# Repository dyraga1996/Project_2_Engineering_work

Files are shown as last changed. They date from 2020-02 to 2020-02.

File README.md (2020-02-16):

# Project_2_Engineering_work
Design and implementation of an access control system using RFID technology. 
The system will consist of three components: 
- an electronic device
- a program written in C++ language for the microcontroller
- a web server on which the Internet application and the MySQL database will be located.

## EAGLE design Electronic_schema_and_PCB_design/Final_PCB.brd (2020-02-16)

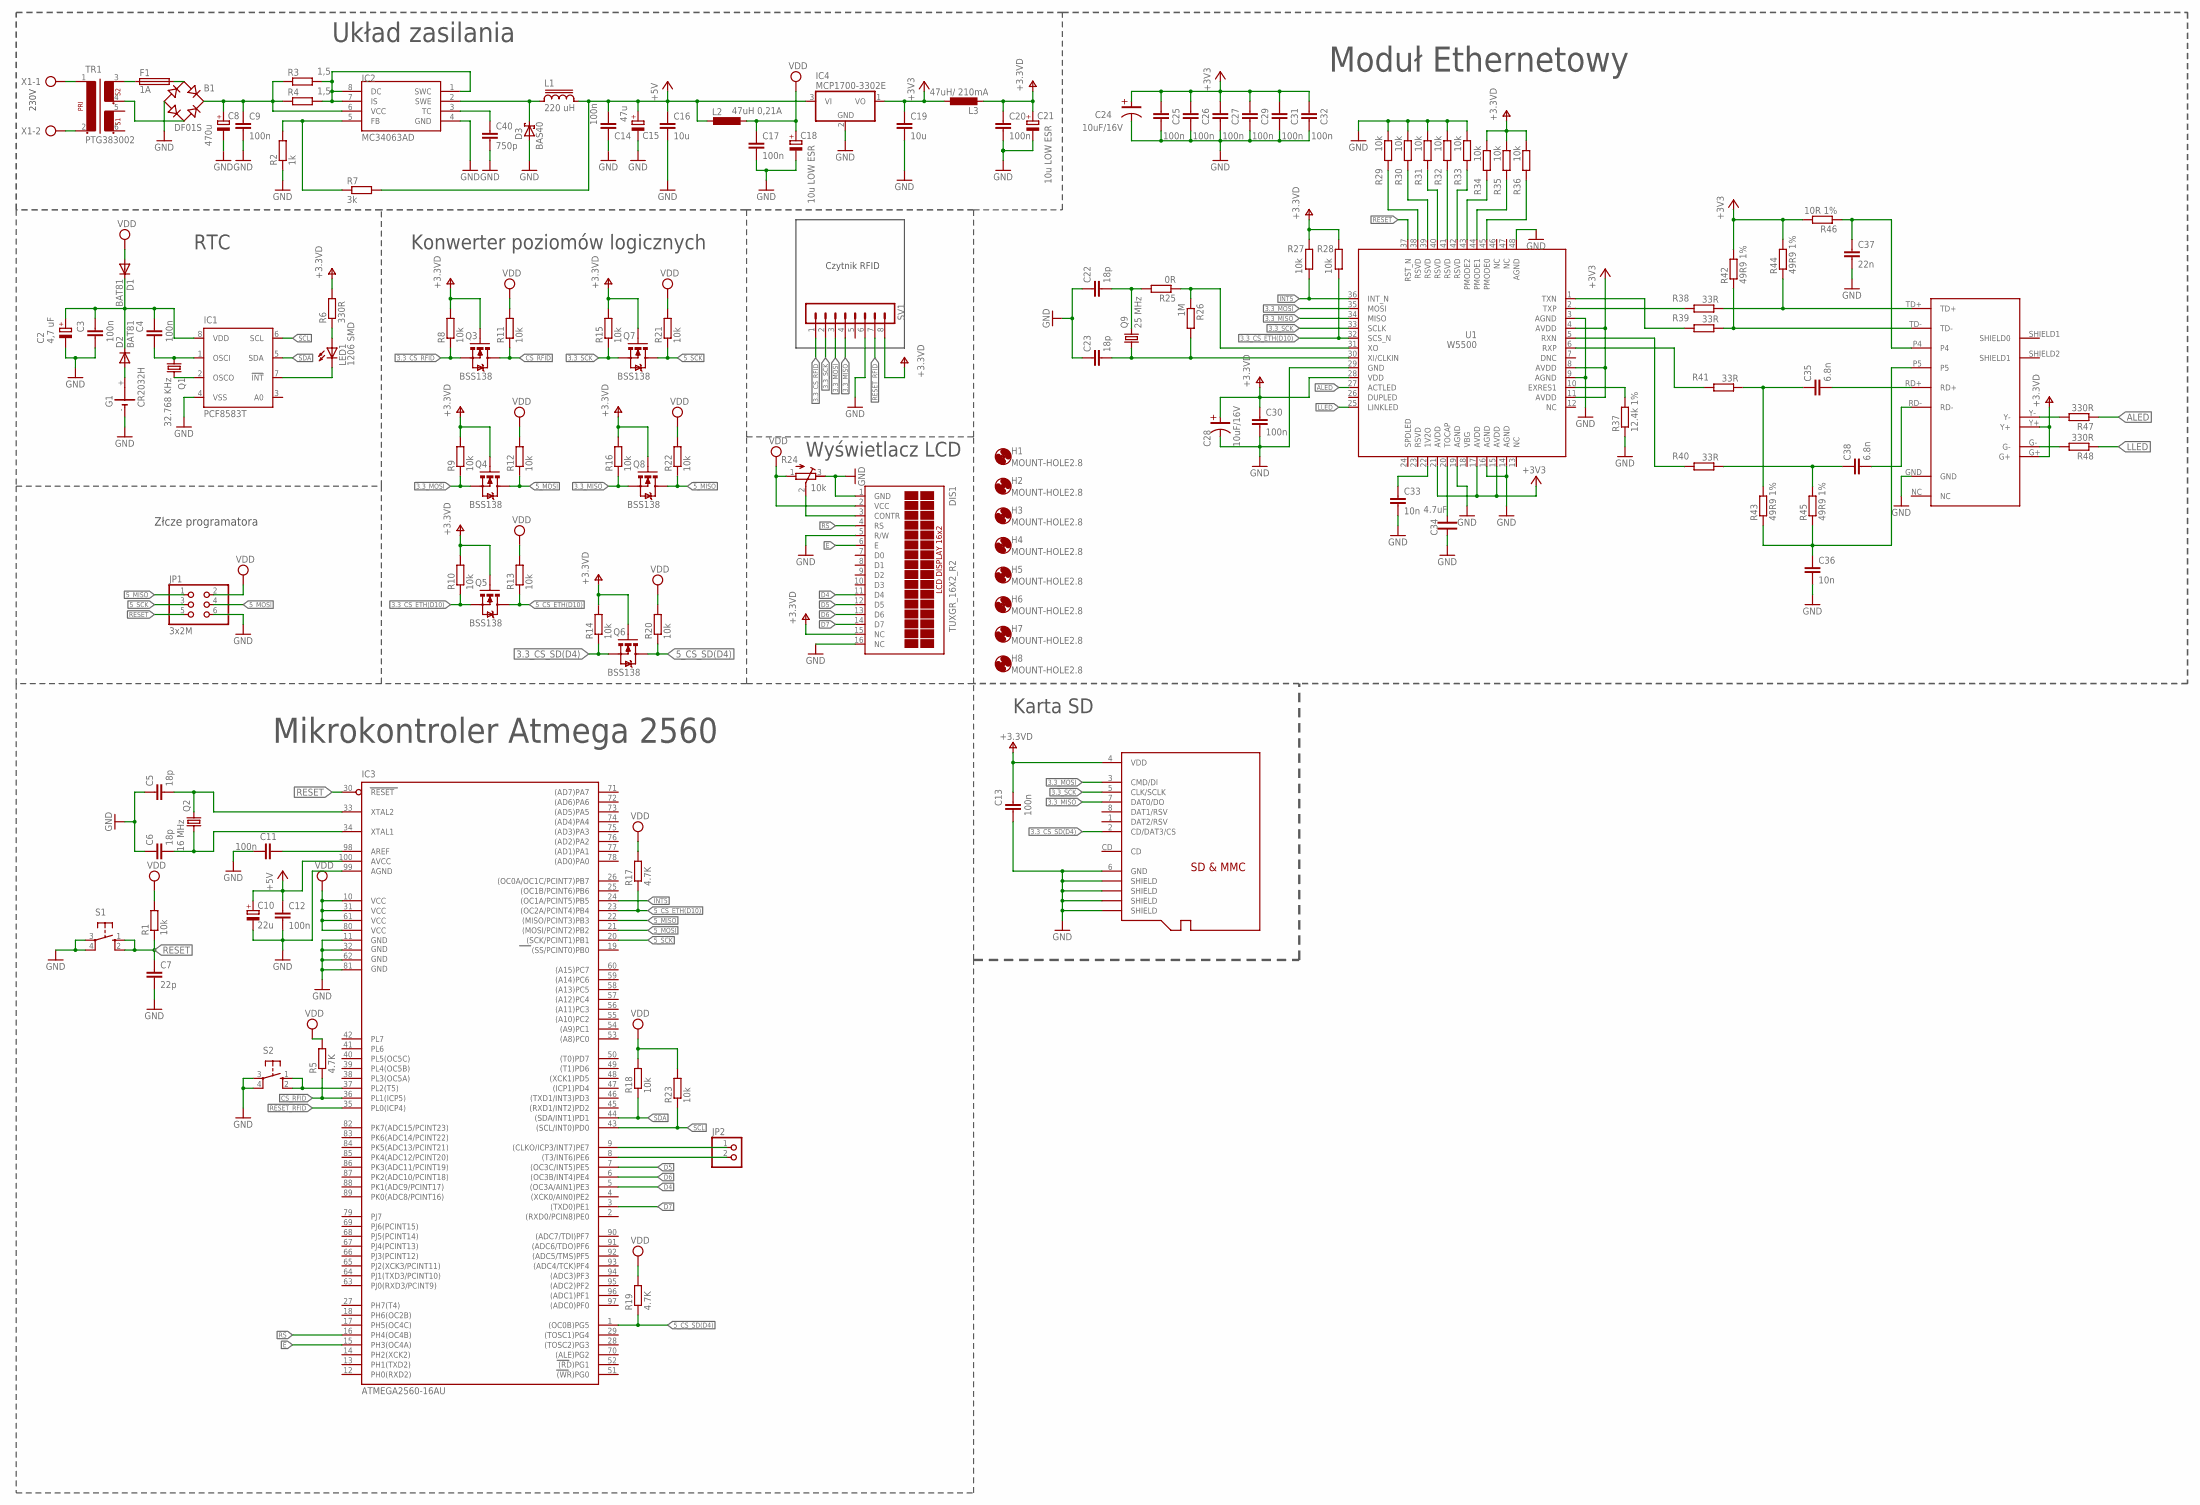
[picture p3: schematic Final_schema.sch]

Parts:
B1: DF01S; DB
C2: 4,7 uF; UD-5X5,8_NICHICON
C3, C4, C9, C12, C13, C14, C25, C26, C27, C29, C31, C32: 100n; C0603
C5, C6, C22, C23: 18p; C0603
C7: 22p; C0603
C8: 470u; E7,5-16
C10: 22u; UD-5X5,8_NICHICON
C11: 100n; C0603-ROUND
C15: 47u; 153CLV-0505
C16, C19: 10u; C0603
C17, C20, C30: 100n; C0603K
C18, C21: 10u LOW ESR; E5-10,5
C24, C28: 10uF/16V; C-3216(TANTAL)
C33, C36: 10n; C0603
C34: 4.7uF; C-2012
C35, C38: 6.8n; C0603
C37: 22n; C0603
C40: 750p; C0603K
D1, D2: BAT81; DO34-7
D3: BAS40; SOT23
DIS1: TUXGR_16X2_R2
F1: 1A; GSH15
G1: CR2032H
H1, H2, H3, H4, H5, H6, H7, H8: MOUNT-HOLE2.8; 2,8
IC1: PCF8583T; SO8-7_5
IC2: MC34063AD; SOIC8
IC3: ATMEGA2560-16AU; TQFP100
IC4: MCP1700-3302E; TO92
JP1: 3x2M; 2X03
JP2: D5; 1X02
L1: 220 uH; CD54
L2: 47uH 0,21A; L1812
L3: 47uH/ 210mA; L1812
LED1: 1206 SMD; LED_1206
Q1: 32.768 KHz; TC26H
Q2: 16 MHz; HC49/S
Q3, Q4, Q5, Q6, Q7, Q8: BSS138; SOT23-3
Q9: 25 MHz; HC49/S
R1, R8, R9, R10, R11, R12, R13, R14, R15, R16, R18, R20, R21, R22, R23, R27, R28, R29, R30, R31, R32, R33, R34, R35, R36: 10k; R0603
R2: 1k; R0603
R3, R4: 1,5; 0411/15
R5, R17, R19: 4.7K; R0603
R6, R47, R48: 330R; R0603
R7: 3k; R0603
R24: 10k; RTRIM4G/J
R25: 0R; R0603
R26: 1M; R0603
R37: 12.4k 1%; R0603
R38, R39, R40, R41: 33R; R0603
R42, R43, R44, R45: 49R9 1%; R0603
R46: 10R 1%; R0603
S1: SW3; B3F-10XX
S2: SW; B3F-10XX
SV1: RC522; MA08-1
TR1: PTG383002; VR12
U1: W5500
U$1: HR911105A; RJ45
U$2: MICROSD; C12075
X1: 230V; AK500/2-H

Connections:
3.3_CS_ETH(D10): Q5.2 (S), R10.1, R28.1, U1.32 (SCS_N)
3.3_CS_RFID: Q3.2 (S), R8.1, SV1.1
3.3_CS_SD(D4): Q6.2 (S), R14.1, U$2.2 (CD/DAT3/CS)
3.3_MISO: Q8.2 (S), R16.1, SV1.4, U1.34 (MISO), U$2.7 (DAT0/DO)
3.3_MOSI: Q4.2 (S), R9.1, SV1.3, U1.35 (MOSI), U$2.3 (CMD/DI)
3.3_SCK: Q7.2 (S), R15.1, SV1.2, U1.33 (SCLK), U$2.5 (CLK/SCLK)
5_CS_ETH(D10): IC3.23 ((OC2A/PCINT4)PB4), Q5.3 (D), R13.1, R17.1
5_CS_SD(D4): IC3.1 ((OC0B)PG5), Q6.3 (D), R19.1, R20.1
5_MISO: IC3.22 ((MISO/PCINT3)PB3), JP1.1, Q8.3 (D), R22.1
5_MOSI: IC3.21 ((MOSI/PCINT2)PB2), JP1.4, Q4.3 (D), R12.1
5_SCK: IC3.20 ((SCK/PCINT1)PB1), JP1.3, Q7.3 (D), R21.1
+3V3: C19.1, C24.1, C25.1, C26.1, C27.1, C29.1, C31.1, C32.1, IC4.1 (VO), L3.1, R42.2, R44.2, R46.2, U1.4 (AVDD), U1.8 (AVDD), U1.11 (AVDD), U1.15 (AVDD), U1.17 (AVDD), U1.21 (AVDD)
+5V: C10.+, C12.1, C14.1, C15.+, C16.1, IC3.100 (AVCC), IC4.3 (VI), L1.2, L2.2, R7.2
ALED: R47.1, U1.27 (ACTLED)
AREF: C11.1, IC3.98 (AREF)
CS_RFID: IC3.36 (PL1(ICP5)), Q3.3 (D), R5.1, R11.1
D4: DIS1.11 (D4), IC3.5 ((OC3A/AIN1)PE3)
D5: DIS1.12 (D5), IC3.7 ((OC3C/INT5)PE5)
D6: DIS1.13 (D6), IC3.6 ((OC3B/INT4)PE4)
D7: DIS1.14 (D7), IC3.3 ((TXD0)PE1)
E: DIS1.6 (E), IC3.15 (PH3(OC4A))
GND: B1.-, C2.-, C3.2, C5.1, C6.1, C7.2, C8.-, C9.2, C10.-, C11.2, C12.2, C13.2, C14.2, C15.-, C16.2, C17.2, C18.-, C19.2, C20.2, C21.-, C22.1, C23.1, C24.2, C25.2, C26.2, C27.2, C28.2, C29.2, C30.2, C31.2, C32.2, C33.2, C34.P$1, C36.2, C37.2, C40.2, D3.1 (A), DIS1.1 (GND), DIS1.5 (R/W), DIS1.16 (NC), G1.-, IC1.4 (VSS), IC2.4 (GND), IC3.11 (GND), IC3.32 (GND1), IC3.62 (GND2), IC3.81 (GND3), IC3.99 (AGND), IC4.2 (GND), JP1.6, R2.1, R24.3 (E), R29.2, R30.2, R31.2, R32.2, R33.2, R37.1, S1.3, S1.4 (P1), S2.3, S2.4 (P1), SV1.6, U1.3 (AGND), U1.9 (AGND), U1.14 (AGND), U1.16 (AGND), U1.19 (AGND), U1.29 (GND), U1.48 (AGND), U$1.GND, U$2.6 (GND), U$2.GND@1 (SHIELD), U$2.GND@2 (SHIELD), U$2.GND@3 (SHIELD), U$2.GND@4 (SHIELD)
INT5: IC3.24 ((OC1A/PCINT5)PB5), R27.1, U1.36 (INT_N)
LLED: R48.1, U1.25 (LINKLED)
unnamed: IC1.7 (!INT), LED1.C
unnamed: R29.1, U1.38 (RSVD)
unnamed: IC2.5 (FB), R2.2, R7.1
unnamed: IC2.1 (SWC), IC2.7 (IS), IC2.8 (DC), R3.2, R4.2
unnamed: D3.3 (C), IC2.2 (SWE), L1.1
unnamed: C40.1, IC2.3 (TC)
unnamed: TR1.1, X1.1
unnamed: TR1.2, X1.2
unnamed: B1.AC1, F1.2
unnamed: B1.AC2, TR1.4 (5)
unnamed: F1.1, TR1.3 (6)
unnamed: B1.+, C8.+, C9.1, IC2.6 (VCC), R3.1, R4.1
unnamed: R47.2, U$1.Y-
unnamed: R41.2, U1.6 (RXP)
unnamed: DIS1.3 (CONTR), R24.2 (S)
unnamed: R30.1, U1.39 (RSVD)
unnamed: R31.1, U1.40 (RSVD)
unnamed: C22.2, Q9.2, R25.2
unnamed: IC3.9 ((CLKO/ICP3/INT7)PE7), JP2.1
unnamed: IC3.8 ((T3/INT6)PE6), JP2.2
unnamed: R48.2, U$1.G-
unnamed: IC3.37 (PL2(T5)), S2.1 (S), S2.2 (S1)
unnamed: C4.2, IC1.1 (OSCI), Q1.1
unnamed: IC1.2 (OSCO), Q1.2
unnamed: D2.A, G1.+
unnamed: C2.+, C3.1, C4.1, D1.C, D2.C, IC1.8 (VDD)
unnamed: R32.1, U1.41 (RSVD)
unnamed: R33.1, U1.42 (RSVD)
unnamed: R34.1, U1.43 (PMODE2)
unnamed: R35.1, U1.44 (PMODE1)
unnamed: R36.1, U1.45 (PMODE0)
unnamed: C34.P$2, U1.20 (TOCAP)
unnamed: C33.1, U1.22 (1V2O)
unnamed: R37.2, U1.10 (EXRES1)
unnamed: C37.1, R46.1, U$1.P4
unnamed: C35.2, U$1.RD+
unnamed: C38.2, U$1.RD-
unnamed: C36.1, R43.1, R45.1, U$1.P5
unnamed: LED1.A, R6.1
unnamed: R25.1, R26.1, U1.31 (XO)
unnamed: R40.2, U1.5 (RXN)
unnamed: R38.2, U1.2 (TXP)
unnamed: R39.2, U1.1 (TXN)
unnamed: C23.2, Q9.1, R26.2, U1.30 (XI/CLKIN)
RESET: C7.1, IC3.30 (RESET), JP1.5, R1.1, S1.1 (S), S1.2 (S1), U1.37 (RST_N)
RESET_RFID: IC3.35 (PL0(ICP4)), SV1.7
RS: DIS1.4 (RS), IC3.16 (PH4(OC4B))
RXN: C38.1, R40.1, R45.2
RXP: C35.1, R41.1, R43.2
SCL: IC1.6 (SCL), IC3.43 ((SCL/INT0)PD0), R23.1
SDA: IC1.5 (SDA), IC3.44 ((SDA/INT1)PD1), R18.1
TXN: R39.1, R42.1, U$1.TD-
TXP: R38.1, R44.1, U$1.TD+
V+: C13.1, C20.1, C21.+, C28.1, C30.1, DIS1.15 (NC), L3.2, Q3.1 (G), Q4.1 (G), Q5.1 (G), Q6.1 (G), Q7.1 (G), Q8.1 (G), R6.2, R8.2, R9.2, R10.2, R14.2, R15.2, R16.2, R27.2, R28.2, R34.2, R35.2, R36.2, SV1.8, U1.28 (VDD), U$1.G+, U$1.Y+, U$2.4 (VDD)
VDD: C17.1, C18.+, D1.A, DIS1.2 (VCC), IC3.10 (VCC), IC3.31 (VCC1), IC3.61 (VCC2), IC3.80 (VCC3), JP1.2, L2.1, R1.2, R5.2, R11.2, R12.2, R13.2, R17.2, R18.2, R19.2, R20.2, R21.2, R22.2, R23.2, R24.1 (A)
XTAL1: C6.2, IC3.34 (XTAL1), Q2.1
XTAL2: C5.2, IC3.33 (XTAL2), Q2.2

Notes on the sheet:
230V
Układ zasilania
Czytnik RFID
Wyświetlacz LCD
Konwerter poziomów logicznych
RTC
Karta SD
Złcze programatora
Moduł Ethernetowy
Mikrokontroler Atmega 2560

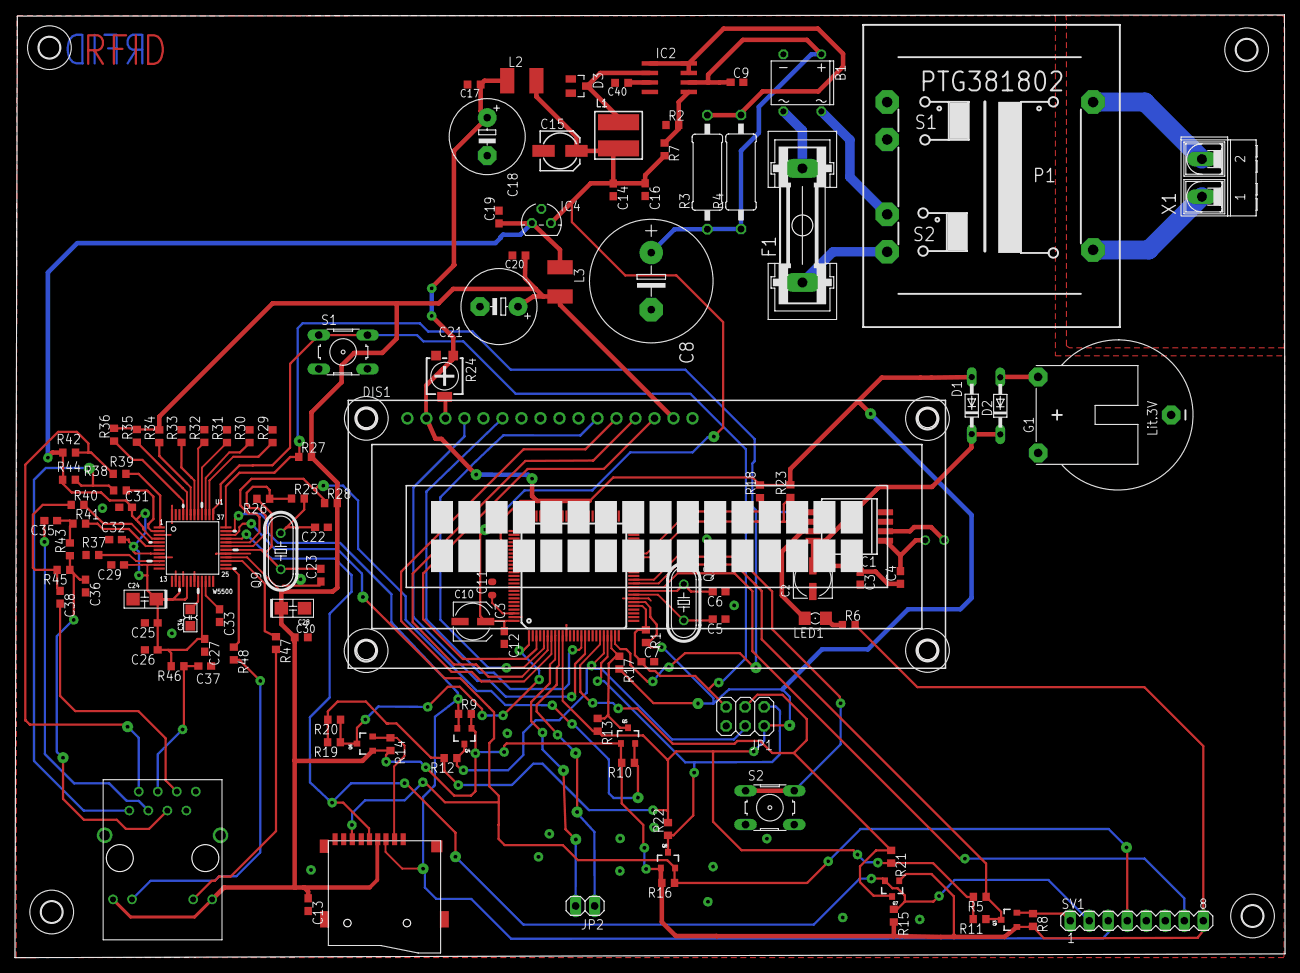
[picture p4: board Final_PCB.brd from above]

Board: 2 copper layers, 169.7 x 126.0 mm, 128 parts (1 on the bottom side), 81 nets.

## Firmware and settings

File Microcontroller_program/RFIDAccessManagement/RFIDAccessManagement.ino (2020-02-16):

/*
 * RFIDAccessManagement.ino
 *
 * Created: 9/12/2018 1:32:53 PM
 * Author: Michał Dyraga
 */
 
/********************************************************************************

Connecting pins to the RC522 reader:
    RST          49
    SDA(SS)      48
    MOSI         51
    MISO         50
    SCK          52

Connecting pins to the LCD display:
    RS  pin 7
    Enable  pin 6
    D4 pin 5
    D5 pin 3
    D6 pin 2
    D7 pin 1
    R/W pin to ground
    VSS pin to ground
    VCC pin to 5V
    10K resistor to V0
    
Connecting pins to the SD card:
    MOSI - pin 51
    MISO - pin 50
    SCK - pin 52
    CS - pin 4

Connecting pins to Ethernet:
    MOSI - pin 51
    MISO - pin 50
    SCK - pin 52
    CS - pin 12 (10 lub 23)

Connecting pins to the RTC clock:
   SDA - SDA
   SCL - SCL
     
****************************************************************************/   
 
/* ********************************* LIBRARY DEFINITION ********************* */
#include <SPI.h>
#include <Ethernet.h>
#include <MFRC522.h>
#include <LiquidCrystal.h>
// To SD card:
#include <SD.h>
#include <Wire.h>
// To RTC:
#include <PCF8583.h>
#include <stdio.h>
//To Timers:
#include "Timers.h"
/* ********************************* GLOBAL VARIABLES DEFINITION ********************* */
//DEFINE OPTIONS
#define LCD_REFRESH 100
#define ETH_CONN_REFRESH 500

//Button Constants
const byte BTN = 47;

// LCD Constants
const byte RS = 7;
const byte EN = 6;
const byte D4 = 5;
const byte D5 = 3;
const byte D6 = 2;
const byte D7 = 1;
// LCD Model
LiquidCrystal lcd(RS, EN, D4, D5, D6, D7);
// Ethernet Conf Variables
byte mac[] = { 0xD0, 0xFB, 0xFE, 0xEF, 0xC4, 0xEA };
char server[] = "rfid-management.pl"; //Server for our API
// Ethernet Model
EthernetClient client;
// RFID Constants
const byte CS_PIN = 48;
const byte RST_P = 49;
//byte ID[4]; //Variable which contains readed key
// RFID Model
MFRC522 rfid(CS_PIN, RST_P);
MFRC522::MIFARE_Key key; //Key initialization
// RTC Model
int correct_address = 0;
PCF8583 p (0xA0);
//Timers
Timer refreshLCDTimer; //Timer to control LCD
Timer refreshEthernetStatus;

/* END OF Global Variables */

//Definition of functions
void lcdControl(byte option, char text[]=0, byte vertical=5, byte horizontal=5); //Control Display on/off/clear/something else
boolean initSDCard( void ); //Initialization of SD Card
void writeSDCard(byte array[]); //Write logs to SD Card when server is offline
boolean parseSDData( void );
void SetTime(void);

boolean getRfidId(byte *buffor, byte buffor_size); //Prepare RFID ID to GET Connection
//ETH Functions
boolean ethernetBeginAuthorize(byte array[]);
boolean testConnection(void);
boolean ethernetBeginAdd(byte array[]);


//Local Variables

boolean grantedFlag; //Authorization granted flag
boolean onlyOneTimerFlag; //Flag to check if timer was used
boolean ethFlag; //Flag to check if ethernet Connection is estabilished
boolean onlyOneErrorFlag; //Flag to avoid loop in Ethernet Connection Error!
boolean ethStatus; //Boolean variable containing ethStatus.
String answear = ""; //Prepared string with API Answear which uC is searched for prepared strings
char characterReceived; //Characters received from API
boolean result;
String timeData[100];  
String cardData[100];
String actionData[100];
String suckData;
byte iteration;
byte sequence; 


void setup()
{
  pinMode(BTN, INPUT_PULLUP);
    lcd.begin(16, 2);
    lcd.clear();
	  //Author section
    lcdControl(2, "V.2 Produced by");
    lcdControl(2, "Michal Dyraga", 1,0);
	  delay(100);
	  lcd.clear();
    lcdControl(2, "Inicjalizacja...");
    //RFID and Ethernet Initialization over SPI
    SPI.begin();
    rfid.PCD_Init();
    //ETH Initialization
    Ethernet.begin(mac);
	  //SetTime();           
    ethStatus = testConnection();   
	lcd.clear();
}
 
void loop()
{  
	//Every single loop start - Set new datetime.
	lcdControl(3, 0, 1, 0);
	if (onlyOneTimerFlag == false)
	{
		if(refreshLCDTimer.available()) {
			lcdControl(1);
			onlyOneTimerFlag = true;
		}
	}
	if(ethFlag == false) {
		if (refreshEthernetStatus.available())
		{
			onlyOneErrorFlag = false;
			ethStatus = testConnection();
			refreshEthernetStatus.restart();
		}
	}
	       
    if(rfid.PICC_IsNewCardPresent() && rfid.PICC_ReadCardSerial())
    {
        ethStatus = getRfidId(rfid.uid.uidByte, rfid.uid.size); 
		
		rfid.PICC_HaltA();
		rfid.PCD_StopCrypto1();  
	} else {
		if(ethFlag != false) {
			ethStatus = true;
		}
	}
	
	if(ethStatus) { //Section where we handle eth connection responses
		if (client.available())
		{
			while (client.available() > 0) {
				characterReceived = client.read();
				answear += characterReceived;
       Serial.print(characterReceived);
			}
			} else {
			answear = "";
		}
		
		//Authentication's ifs
		if(grantedFlag == false) {
			if( answear.indexOf("Error") > 0 ) {
				lcdControl(2, "Brak autoryzacji");
				//Make refresh time for LCD and set flag to avoid accidentaly grant authorization
				grantedFlag = true;
				onlyOneTimerFlag = false;
				refreshLCDTimer.begin(LCD_REFRESH);
			}
				
			if( answear.indexOf("Access") > 0) {
				lcdControl(2, "Autoryzacja");      
				grantedFlag = true;
				onlyOneTimerFlag = false;
				refreshLCDTimer.begin(LCD_REFRESH);
			}
			
			//TestETH ifs
			if( answear.indexOf("Connected") > 0) {
				lcdControl(2, "Polaczenie OK");
				grantedFlag = true;
				onlyOneTimerFlag = false;
				refreshLCDTimer.begin(LCD_REFRESH);
       
				if(SD.exists("LOGI.TXT"))  {
        
				   prepareSDData();  
				  }
				ethFlag = true;
			}
			
			//Card add if
			if( answear.indexOf("Added OK") > 0) {
        lcd.clear();
				lcdControl(2, "Dodano!");
				grantedFlag = true;
				onlyOneTimerFlag = false;
				refreshLCDTimer.begin(LCD_REFRESH);
			}
				
		}
	} else { //Section where we handle error with Ethernet Connection
		if(onlyOneErrorFlag == false) {
			refreshLCDTimer.begin(LCD_REFRESH);
			refreshEthernetStatus.begin(ETH_CONN_REFRESH);
			onlyOneErrorFlag = true;
			
			lcdControl(2, "Blad autoryzacji");
			ethFlag = false;
		}
	}
	
	//Flush for flags etc.
	grantedFlag = false;
}
 
boolean getRfidId(byte *buffor, byte buffor_size)
{
    byte newArray[4];
   
    for (byte i = 0; i < buffor_size; i++)
    {
        newArray[i] = buffor[i];        
    }

    

    if(digitalRead(47) == LOW){
	ethStatus = ethernetBeginAdd(newArray);
	} else {
    ethStatus = ethernetBeginAuthorize(newArray);
	}
	if (ethStatus == false)
	{
		  writeSDCard(newArray);
	}
	return ethStatus;
}
 
// Function connect to server,
boolean ethernetBeginAuthorize(byte array[]) {
	lcdControl(2, "Komunikacja...");
    if (client.connect(server, 80)) {
        // Make a HTTP request:
        client.print("GET /access/");
		for(byte i=0; i < 4; i++)
		{
		    client.print(array[i], HEX);
		}
		client.println(" HTTP/1.1");
        client.println("Host: rfid-management.pl");
        client.println("Connection: close");
        client.println();
		
		return true;
    }
   
    if (!client.connected()) {
		
        if(!client.connect(server,80)) {
			
        }
		
        return false;
        } 
}
 
boolean testConnection(void) {
  lcd.clear();
	lcdControl(2, "Test ETH...");
	client.stop();
	if (client.connect(server, 80)) {
		// Make a HTTP request:
		client.println("GET /test_connection/ HTTP/1.1");
		client.println("Host: rfid-management.pl");
		client.println("Connection: close");
		client.println();
		
		return true;
	}
	
	if (!client.connected()) {
		
		if(!client.connect(server,80)) {
		}
		
		return false;
	}
}

boolean ethernetBeginAdd(byte array[]) {
  lcdControl(2, "Dodawanie...");
  if (client.connect(server, 80)) {
	  // Make a HTTP request:
	  client.print("GET /rfid/temp/");
	  for(byte i=0; i < 4; i++)
	  {
		  client.print(array[i], HEX);
	  }
	  client.println(" HTTP/1.1");
	  client.println("Host: rfid-management.pl");
	  client.println("Connection: close");
	  client.println();
	  
	  return true;
  }
  
  if (!client.connected()) {
	  
	  if(!client.connect(server,80)) {
	  }
	  
	  return false;
  }
}

boolean ethernetSynchronizeLogs(String timeData,String cardData,String actionData) {
  if (client.connect(server, 80)) {
    // Make a HTTP request:

    client.print("GET /logs/synchronize/");
    client.print(timeData);
    client.print("/");
    client.print(cardData);
    client.print("/");
    client.print(actionData);
    client.println(" HTTP/1.1");
    client.println("Host: rfid-management.pl");
    client.println("Connection: close");
    client.println();
   
    return true;
  }
 
  if (!client.connected()) {
   
    if(!client.connect(server,80)) {
     
    }
   
    return false;
  }
}

boolean prepareSDData() {
  File myFile;
  myFile = SD.open("LOGI.TXT");
 
  if (myFile) {
    sequence = 0;
    iteration = 0;
    // read from the file until there's nothing else in it:
    while (myFile.available()) {
      if( sequence == 0) {
        timeData[iteration] = myFile.readStringUntil(';');
      }
      else if( sequence == 1 ) {
        cardData[iteration] = myFile.readStringUntil(';');
      }
      else if( sequence == 2 ) {
        actionData[iteration] = myFile.readStringUntil(';');
      }
      else if( sequence == 3 ) {
        suckData = myFile.readStringUntil('\n');
      }
      sequence++;
      if(sequence > 3) {
        sequence = 0;
        iteration++;
      }
    }
     
    for(byte i = 0; i<iteration; i++) {
      
 
      result = ethernetSynchronizeLogs(timeData[i], cardData[i], actionData[i]);
 
      timeData[i] = "";
      cardData[i] = "";
      actionData[i] = "";
    }
    suckData = "";

    SD.remove("LOGI.TXT");
}
}
void lcdControl(byte option, char text[], byte vertical, byte horizontal) {
	lcd.print("                ");
	lcd.setCursor(0,0);
	if( (vertical != 5) && (horizontal != 5) ) {
		lcd.setCursor(horizontal, vertical);
	}
	if(option == 1) {
		lcd.print("Zbliz karte...");
	}
	if(option == 2) {
		if(text != 0) {
			lcd.print(text);
		}
	}
	if(option == 3) {
		p.get_time();
		char time[50];
		sprintf(time, "%02d/%02d/%02d   %02d:%02d",
		p.day, p.month, p.year, p.hour, p.minute);
		lcd.print(time);
	}
}

/*
Function for change datetime. If you want change timezone or smth. Anyway - USELESS
*/
//void SetTime(void){
//  p.year = 19;
//  p.month = 01;
//  p.day = 29;
//  p.hour = 19;
//  p.minute = 47;
//  p.second = 00;
// p.set_time();
//} 

void writeSDCard(byte array[]){
    File myFile;
    initSDCard();
    myFile = SD.open("LOGI.txt", FILE_WRITE);                                         
    if (myFile) {
		p.get_time();
		char time[50];
		sprintf(time, "%02d-%02d-%02d %02d:%02d:%02d",
		p.year, p.month, p.day, p.hour, p.minute, p.second);
		myFile.print(time);

    myFile.print(";");
    for(int i=0; i<4; i++){
      myFile.print( array[i], HEX);
      }
      
		myFile.print(";");
		myFile.print("Access");
		myFile.print(";");
		myFile.close();
		lcdControl(2, "Wejście zapisane");
  } 
}

boolean initSDCard(){
  if (!SD.begin(4)) {
	  return false;
  } else {
	  return true;
  }
}

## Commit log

2020-02-16 Final schema
    [Final_schema.sch]
2020-02-16 final board PCB
    [Final_PCB.brd]
2020-02-16 Final version internet application with MySQL database
    [index.csv]

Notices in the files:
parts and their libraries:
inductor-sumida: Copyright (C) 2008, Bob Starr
